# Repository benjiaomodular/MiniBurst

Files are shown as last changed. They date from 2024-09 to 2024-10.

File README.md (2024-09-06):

# MiniBurst
[][cc-by-sa]

## License

This work is licensed under a
[Creative Commons Attribution-ShareAlike 4.0 International License][cc-by-sa].

[][cc-by-sa]

[cc-by-sa]: http://creativecommons.org/licenses/by-sa/4.0/
[cc-by-sa-image]: https://licensebuttons.net/l/by-sa/4.0/88x31.png
[cc-by-sa-shield]: https://img.shields.io/badge/License-CC%20BY--SA%204.0-lightgrey.svg

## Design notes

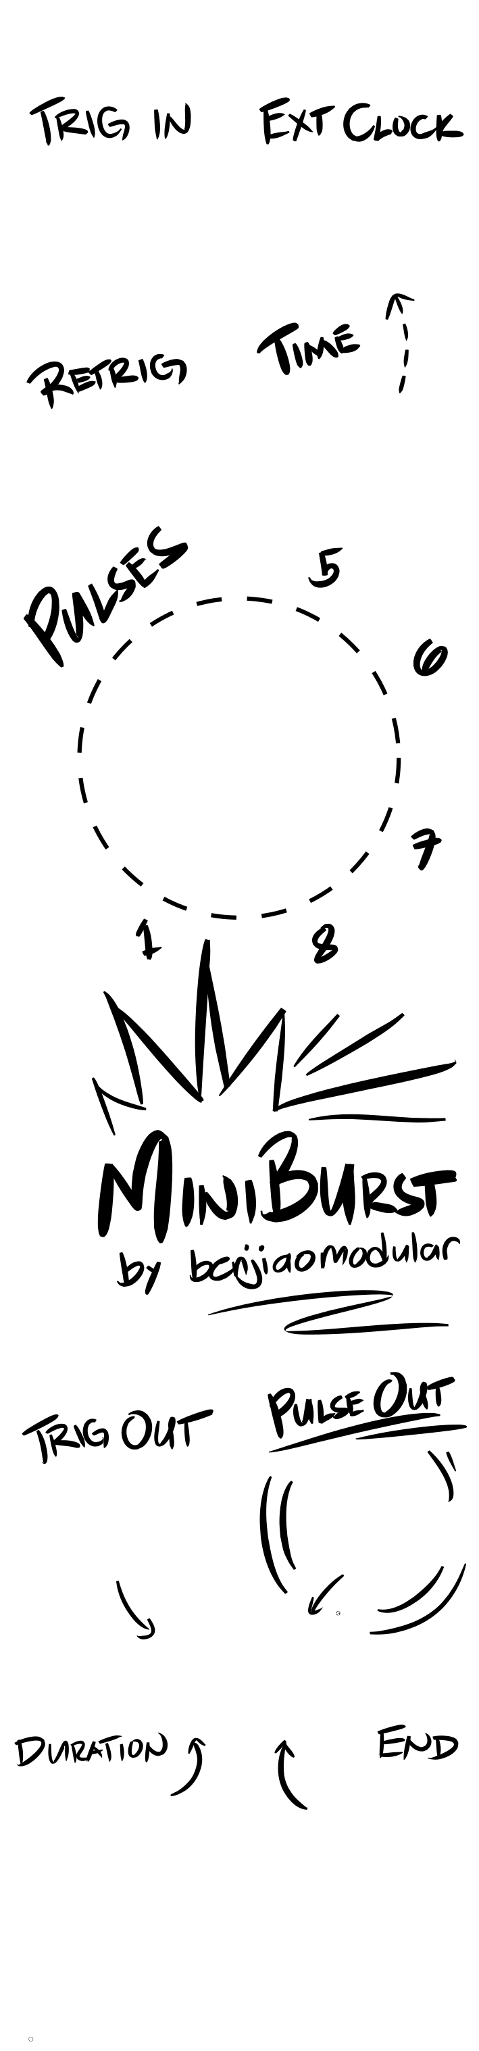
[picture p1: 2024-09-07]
hardware/panel/MiniBurst - Panel.png

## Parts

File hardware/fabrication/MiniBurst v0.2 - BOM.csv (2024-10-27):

null | Placed | References | Value | Footprint | URL | Manufacturer | Part # | Quantity
1 | ✓ | C5, C6, C7, C8, C9 | 100nF | C_0805_2012Metric_Pad1.18x1.45mm_HandSolder | https://mou.sr/4ekMsbM |  |  | 5
2 | ✓ | C3, C4 | 22uF | CP_Elec_4x3.9 | https://mou.sr/4ekMqRc |  |  | 2
3 | ✓ | C1 | 10nF | C_0805_2012Metric_Pad1.18x1.45mm_HandSolder | https://mou.sr/47sqUbk |  |  | 1
4 | ✓ | C2 | 10uF | C_0805_2012Metric_Pad1.18x1.45mm_HandSolder | https://mou.sr/4e5fI6P |  |  | 1
5 | ✓ | R3, R15, R16, R17, R18, R19, R20, R21, R22, R23, R24, R25, R26, R27 | 10k | R_0805_2012Metric | https://mou.sr/3MINYsI |  |  | 14
6 | ✓ | R2, R4, R5, R6, R8, R10, R12 | 100k | R_0805_2012Metric | https://mou.sr/4el3qXS |  |  | 7
7 | ✓ | R7, R11, R13, R14 | 1k | R_0805_2012Metric | https://mou.sr/3MKtPCB |  |  | 4
8 | ✓ | R1, R9 | 15k | R_0805_2012Metric | https://mou.sr/47pyvY3 |  |  | 2
9 |  | D6, D8, D9, D10, D11, D12, D13, D14, D15, D16, D17, D18 | LED | LED_D3.0mm | https://www.taydaelectronics.com/led-3mm-orange.html |  |  | 12
10 | ✓ | D1, D2, D3, D4, D5, D7 | 1N4148 | D_SOD-123 | https://mou.sr/3XEhTbD |  |  | 6
11 | ✓ | U1, U4, U5 | LM358 | SOIC-8_5.23x5.23mm_P1.27mm | https://mou.sr/4dWmV9p |  |  | 3
12 | ✓ | U2 | 40106 | SOIC-14_3.9x8.7mm_P1.27mm | https://mou.sr/47m5xIo |  |  | 1
13 | ✓ | U3 | 4017 | SOIC-16W_5.3x10.2mm_P1.27mm | https://mou.sr/3BQ06Wp |  |  | 1
14 |  | SW2 | STEPS | RotarySwitch_SR16_POLE1_WAY8 | https://www.aliexpress.com/i/32952531277.html |  |  | 1
15 |  | SW3 | SW_DPDT_x2 | Button_KFC7x7 | https://www.taydaelectronics.com/push-button-switch-dc-30v-0-1a-dpdt-7x7mm.html |  |  | 1
16 |  | RV1 | B100k | Potentiometer_RV09 | https://www.taydaelectronics.com/tayda-100k-ohm-linear-taper-potentiometer-round-shaft-pcb-9mm-6-35-mm.html |  |  | 1
17 |  | J1 | TRIG_IN | AudioJack_3.5mm | https://www.taydaelectronics.com/pj-3001f-3-5-mm-mono-phone-jack.html |  |  | 1
18 |  | J2 | TRIG_OUT | AudioJack_3.5mm | https://www.taydaelectronics.com/pj-3001f-3-5-mm-mono-phone-jack.html |  |  | 1
19 |  | J3 | EXT_CLK | AudioJack_3.5mm | https://www.taydaelectronics.com/pj-3001f-3-5-mm-mono-phone-jack.html |  |  | 1
20 |  | J4 | DURATION_OUT | AudioJack_3.5mm | https://www.taydaelectronics.com/pj-3001f-3-5-mm-mono-phone-jack.html |  |  | 1
21 |  | J5 | END_OUT | AudioJack_3.5mm | https://www.taydaelectronics.com/pj-3001f-3-5-mm-mono-phone-jack.html |  |  | 1
22 |  | J6 | PULSES_OUT | AudioJack_3.5mm | https://www.taydaelectronics.com/pj-3001f-3-5-mm-mono-phone-jack.html |  |  | 1
23 | ✓ | J7 | Conn_01x10_Pin | Header_IDC2x05_NoArrow |  |  |  | 1

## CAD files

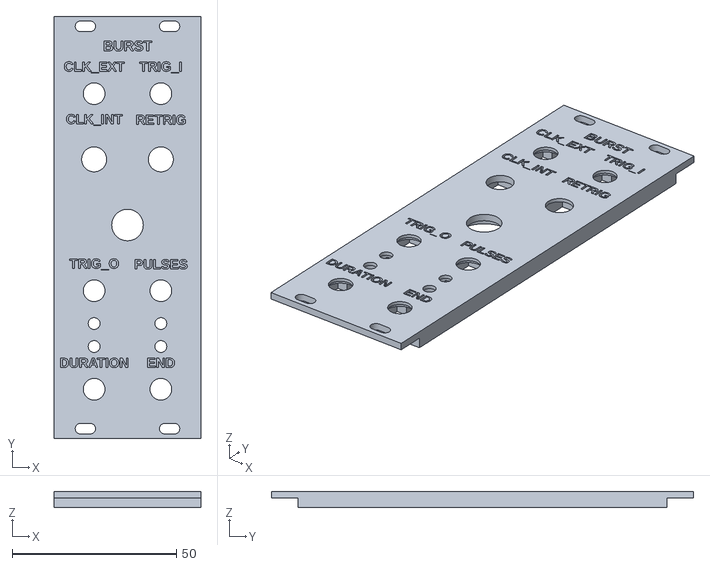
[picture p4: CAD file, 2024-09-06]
hardware/openscad/MiniBurst.stl
44.6 x 128.5 x 5.00

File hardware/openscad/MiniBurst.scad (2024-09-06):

include <EuroPanelMaker/EuroPanelMaker/panel.scad>

hp = 8;
title = "BURST";
text_depth = 1.2;
title_font_size = 3.2;
margin = 2;

pots_rd901f = [
    [2, 85, "CLK_INT"],
];

leds = [
[2, 35, 3],
[2, 28, 3],
[6, 35, 3],
[6, 28, 3],
];

switches_sr16 = [
    [4, 65]
];
keys = [
];


switches = [
    [6, 85, "RETRIG"],
];

jacks = [
    [2, 105, "CLK_EXT"],
    [6, 105, "TRIG_I"],
    [2, 45, "TRIG_O", "35mm", 180],
    [6, 45, "PULSES", "35mm", 180],
    [2, 15, "DURATION", "35mm"],
    [6, 15, "END", "35mm"],
];

generatePanel();

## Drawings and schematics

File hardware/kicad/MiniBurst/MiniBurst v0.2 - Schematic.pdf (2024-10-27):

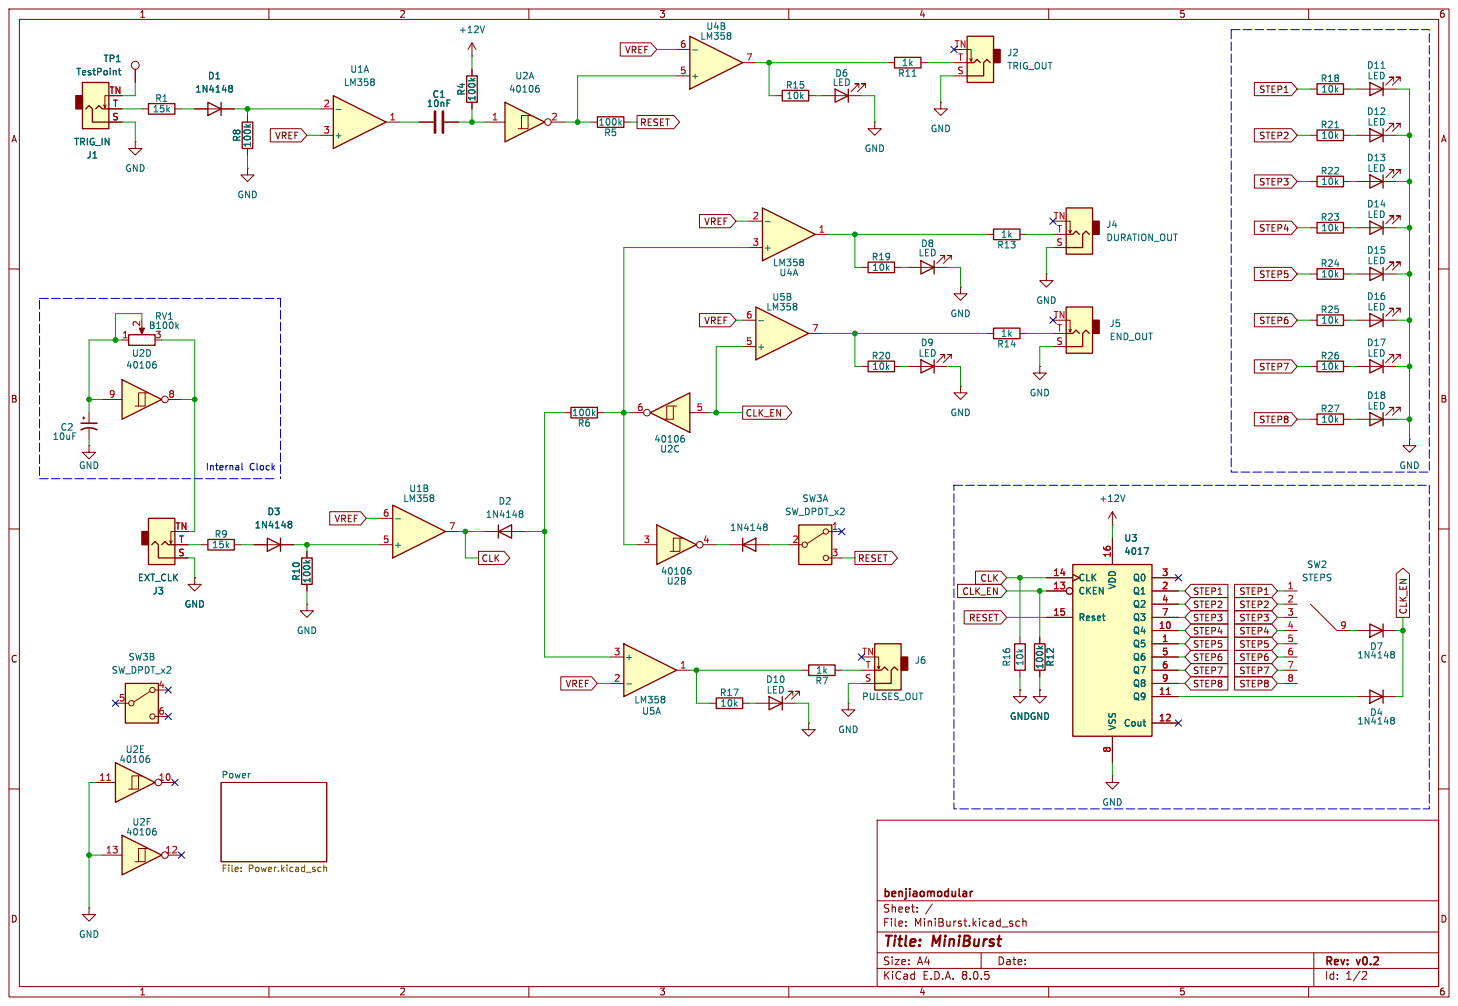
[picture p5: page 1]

Id: 1/2 Title: MiniBurst File: MiniBurst.kicad_sch Sheet: / benjiaomodular Power File: Power.kicad_sch

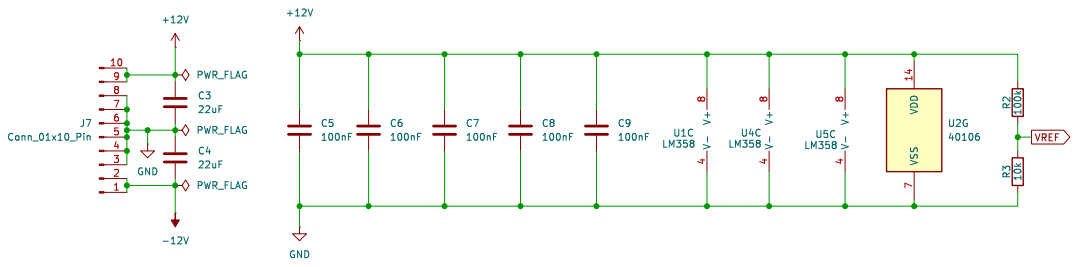
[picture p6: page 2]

Id: 2/2 Title: File: Power.kicad_sch Sheet: /Power/ VDD 14 VSS

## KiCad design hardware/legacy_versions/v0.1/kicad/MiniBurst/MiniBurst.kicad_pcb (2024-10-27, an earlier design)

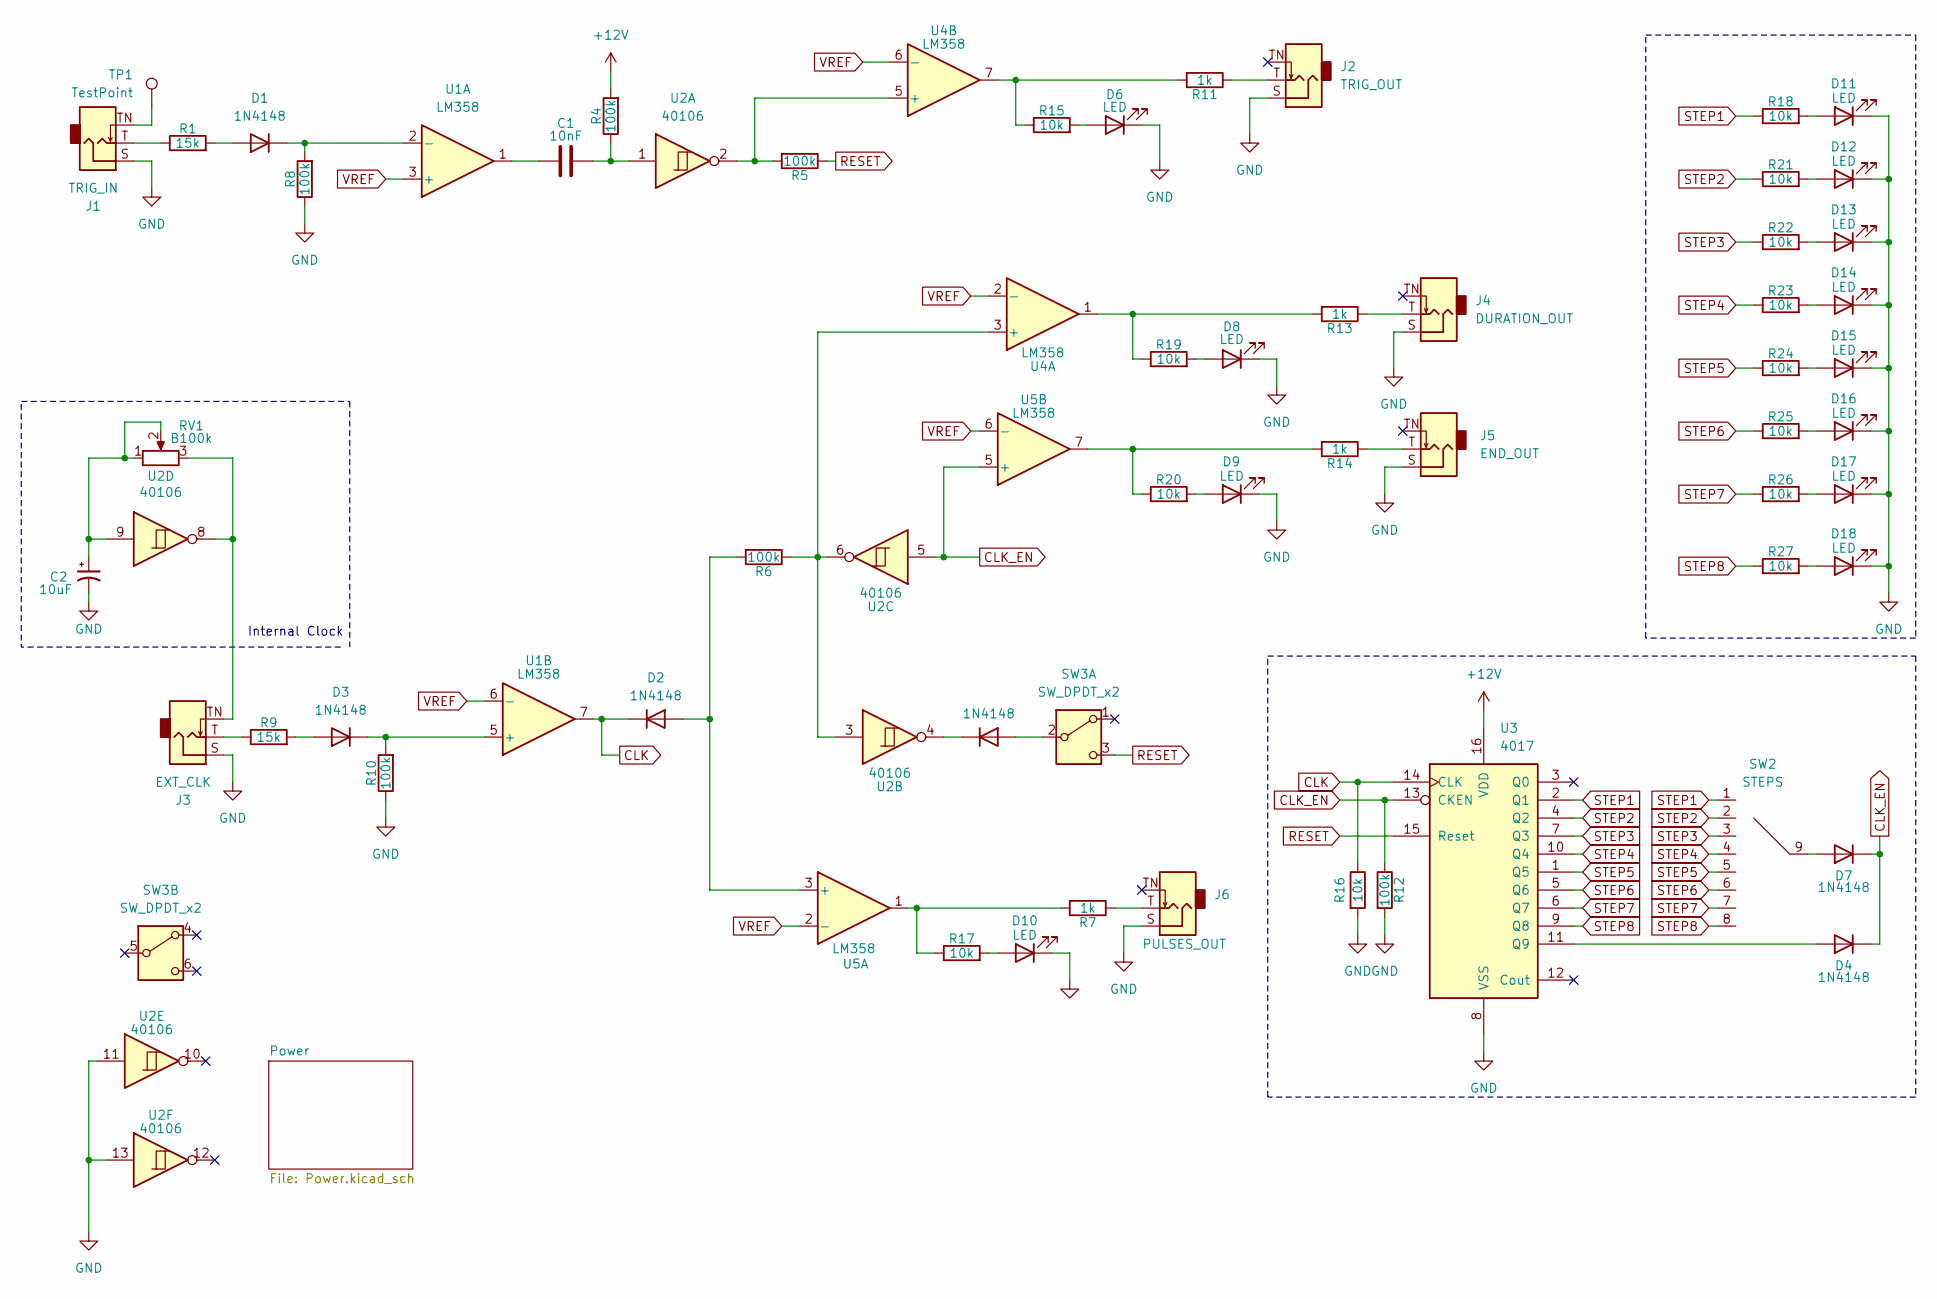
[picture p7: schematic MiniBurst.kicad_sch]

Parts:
C1: 10nF; C_0805_2012Metric_Pad1.18x1.45mm_HandSolder
C2: 10uF; C_0805_2012Metric_Pad1.18x1.45mm_HandSolder; Manufacturers Part Numb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 TMK212BBJ106KG8T
D1, D2, D3, D4, D5, D7: 1N4148; D_SOD-123
D6, D8, D9, D10, D11, D12, D13, D14, D15, D16, D17, D18: LED; LED_D3.0mm
J1: TRIG_IN; AudioJack_3.5mm
J2: TRIG_OUT; AudioJack_3.5mm
J3: EXT_CLK; AudioJack_3.5mm
J4: DURATION_OUT; AudioJack_3.5mm
J5: END_OUT; AudioJack_3.5mm
J6: PULSES_OUT; AudioJack_3.5mm
R1, R9: 15k; R_0805_2012Metric
R4, R5, R6, R8, R10, R12: 100k; R_0805_2012Metric
R7, R11, R13, R14: 1k; R_0805_2012Metric
R15, R16, R17, R18, R19, R20, R21, R22, R23, R24, R25, R26, R27: 10k; R_0805_2012Metric
RV1: B100k; Potentiometer_RV09; Manufacturers Part Numb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 RD901F-40-15R1-B100K
SW2: STEPS; RotarySwitch_SR16_POLE1_WAY8
SW3: SW_DPDT_x2; Button_KFC7x7
TP1: TestPoint; SolderWirePad_1x01_SMD_1x2mm
U1, U4, U5: LM358; SOIC-8_3.9x4.9mm_P1.27mm
U2: 40106; SOIC-14_3.9x8.7mm_P1.27mm
U3: 4017; SOIC-16_3.9x9.9mm_P1.27mm

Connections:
+12V: R4.2, U3.16 (VDD); also elsewhere on the board
CLK: D2.1 (K), R16.1, U1.7, U3.14 (CLK)
CLK_EN: D4.1 (K), D7.1 (K), R12.1, U2.5, U3.13 (CKEN), U5.5 (+)
GND: C2.2, D6.1 (K), D8.1 (K), D9.1 (K), D10.1 (K), D11.1 (K), D12.1 (K), D13.1 (K), D14.1 (K), D15.1 (K), D16.1 (K), D17.1 (K), D18.1 (K), J1.S, J2.S, J3.S, J4.S, J5.S, J6.S, R8.1, R10.1, R12.2, R16.2, U2.11, U2.13, U3.8 (VSS); also elsewhere on the board
unnamed: C1.1, U1.1
unnamed: C1.2, R4.1, U2.1
unnamed: C2.1, RV1.1, RV1.2, U2.9
unnamed: D1.2 (A), R1.2
unnamed: D1.1 (K), R8.2, U1.2 (-)
unnamed: D2.2 (A), R6.2, U5.3 (+)
unnamed: D3.2 (A), R9.2
unnamed: D3.1 (K), R10.2, U1.5 (+)
unnamed: D4.2 (A), U3.11 (Q9)
unnamed: D5.2 (A), SW3.2 (B)
unnamed: D5.1 (K), U2.4
unnamed: D6.2 (A), R15.2
unnamed: D7.2 (A), SW2.9
unnamed: D8.2 (A), R19.2
unnamed: D9.2 (A), R20.2
unnamed: D10.2 (A), R17.2
unnamed: D11.2 (A), R18.2
unnamed: D12.2 (A), R21.2
unnamed: D13.2 (A), R22.2
unnamed: D14.2 (A), R23.2
unnamed: D15.2 (A), R24.2
unnamed: D16.2 (A), R25.2
unnamed: D17.2 (A), R26.2
unnamed: D18.2 (A), R27.2
unnamed: J1.T, R1.1
unnamed: J1.TN, TP1.1
unnamed: J2.T, R11.1
unnamed: J3.T, R9.1
unnamed: J3.TN, RV1.3, U2.8
unnamed: J4.T, R13.1
unnamed: J5.T, R14.1
unnamed: J6.T, R7.1
unnamed: R11.2, R15.1, U4.7
unnamed: R13.2, R19.1, U4.1
unnamed: R14.2, R20.1, U5.7
unnamed: R7.2, R17.1, U5.1
unnamed: R6.1, U2.3, U2.6, U4.3 (+)
unnamed: R5.2, U2.2, U4.5 (+)
RESET: R5.1, SW3.3 (C), U3.15 (Reset)
STEP1: R18.1, SW2.1, U3.2 (Q1)
STEP2: R21.1, SW2.2, U3.4 (Q2)
STEP3: R22.1, SW2.3, U3.7 (Q3)
STEP4: R23.1, SW2.4, U3.10 (Q4)
STEP5: R24.1, SW2.5, U3.1 (Q5)
STEP6: R25.1, SW2.6, U3.5 (Q6)
STEP7: R26.1, SW2.7, U3.6 (Q7)
STEP8: R27.1, SW2.8, U3.9 (Q8)
VREF: U1.3 (+), U1.6 (-), U4.2 (-), U4.6 (-), U5.2 (-), U5.6 (-); also elsewhere on the board

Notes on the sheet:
Internal Clock

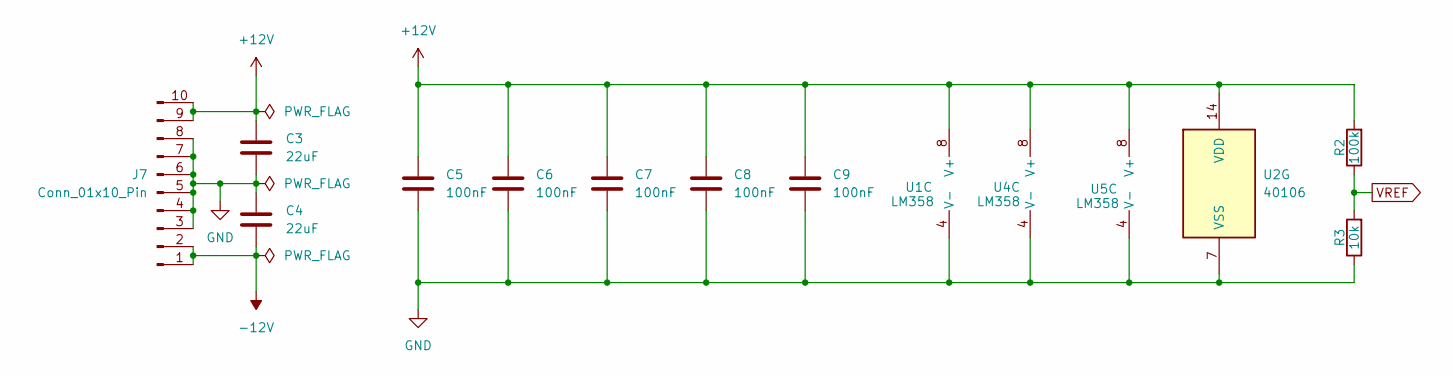
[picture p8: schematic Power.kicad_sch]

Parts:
C3, C4: 22uF; CP_Elec_6.3x4.5; Manufacturers Part Numb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 GRM21BR61E226ME44L
C5, C6, C7, C8, C9: 100nF; C_0805_2012Metric_Pad1.18x1.45mm_HandSolder
J7: Conn_01x10_Pin; Header_IDC2x05_NoArrow
R2: 100k; R_0805_2012Metric
R3: 10k; R_0805_2012Metric
U1, U4, U5: LM358; SOIC-8_3.9x4.9mm_P1.27mm
U2: 40106; SOIC-14_3.9x8.7mm_P1.27mm

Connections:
+12V: C3.1, C5.1, C6.1, C7.1, C8.1, C9.1, J7.9, J7.10, R2.2, U1.8 (V+), U2.14 (VDD), U4.8 (V+), U5.8 (V+); also elsewhere on the board
-12V: C4.2, J7.1, J7.2
GND: C3.2, C4.1, C5.2, C6.2, C7.2, C8.2, C9.2, J7.3, J7.4, J7.5, J7.6, J7.7, J7.8, R3.1, U1.4 (V-), U2.7 (VSS), U4.4 (V-), U5.4 (V-); also elsewhere on the board
VREF: R2.1, R3.2; also elsewhere on the board

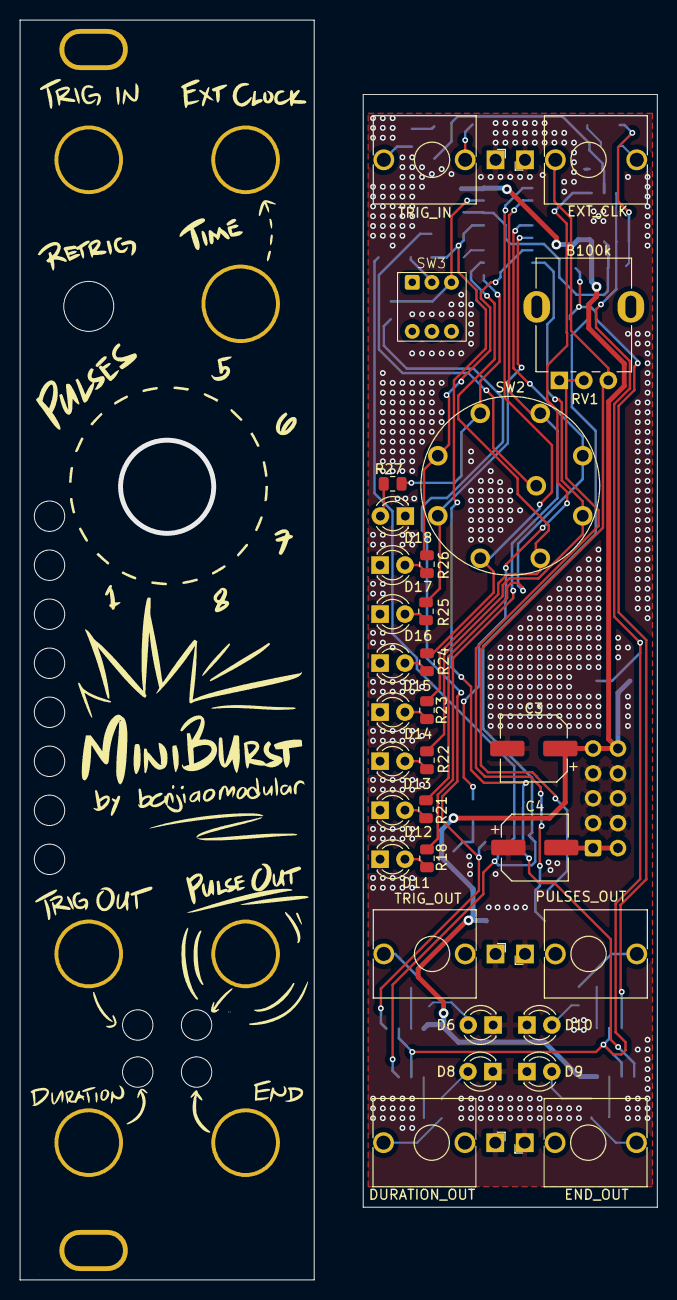
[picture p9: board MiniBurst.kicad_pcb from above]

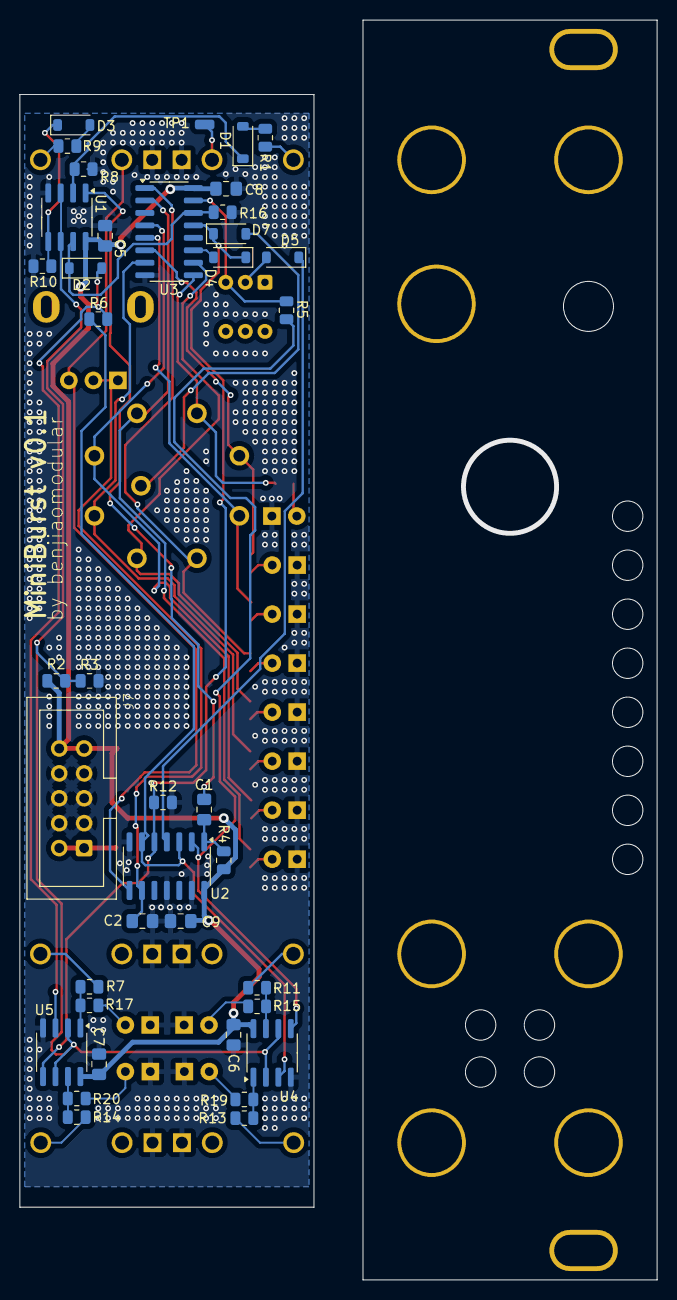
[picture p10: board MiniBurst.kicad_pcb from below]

Board: 2 copper layers, 30.0 x 113.5 mm, 70 parts (39 on the bottom side), 53 nets.

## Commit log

2024-09-06 Reorganized files
    [MiniBurst.kicad_pcb, MiniBurst.kicad_sch, MiniBurst.scad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]
2024-09-07 done with panel art
    [MiniBurst.kicad_pcb, MiniBurst.kicad_sch, Power.kicad_sch]
2024-09-10 v0.1 PCB
    [MiniBurst - Front.kicad_pcb, MiniBurst - Main.kicad_pcb, MiniBurst.kicad_sch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]
2024-09-11 Added copper fill to panel
    [MiniBurst - Panel.kicad_pcb]
2024-10-27 Adjusted main pcb dimensions to fit 3d printed rails
    [MiniBurst - Main.kicad_pcb, MiniBurst - Panel.kicad_pcb, MiniBurst v0.2 - BOM.csv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]
2024-10-28 Added schematics
    [MiniBurst v0.2 - Front.kicad_pcb, MiniBurst v0.2 - Main.kicad_pcb]

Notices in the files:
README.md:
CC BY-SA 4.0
